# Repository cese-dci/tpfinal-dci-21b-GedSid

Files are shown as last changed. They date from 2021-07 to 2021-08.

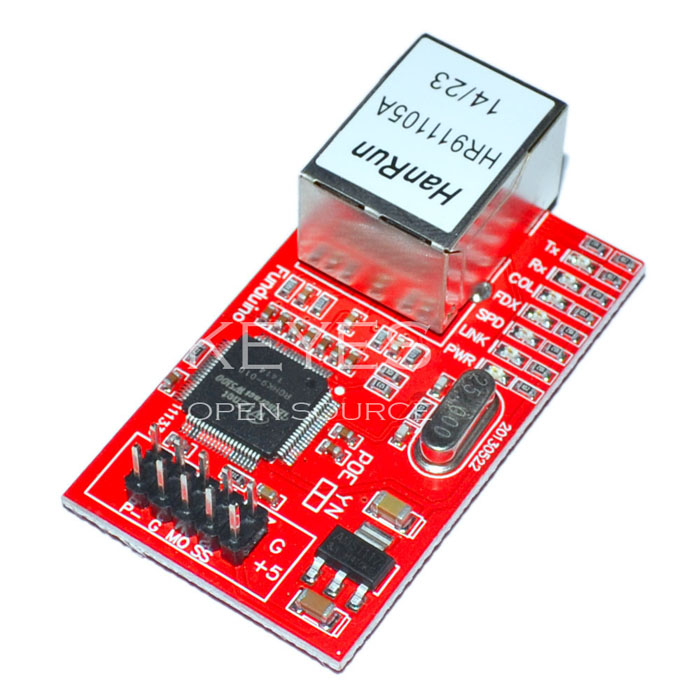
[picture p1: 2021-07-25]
doc/propuesta/Wiznet-w5100-ethernet-module-top.jpg

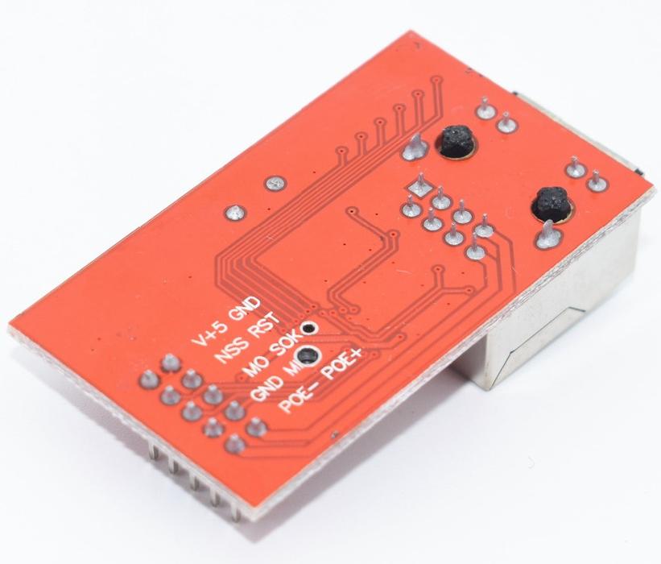
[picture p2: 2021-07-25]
doc/propuesta/Wiznet-w5100-ethernet-module-botton.jpg

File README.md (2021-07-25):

## Trabajo práctico final de la asignatura DCI ##
Este repositorio contiene el trabajo práctico final para la asignatura de Diseño de Circuitos Impresos de la carrera de posgrado de FIUBA.

* Autor: JOAQUIN ULLOA
* Título corto del trabajo:  Réplica Módulo Ethernet W5100 Mini
* Descripción:  La placa tiene un regulador de tensión, por lo que puede se pueden usar tensiones de entrada de 5 V a 12 V. Los pines de señal admiten niveles de 3,3 V y 5 V. El Módulo Ethernet tiene un conector RJ-45 estándar, con un transformador de línea integrado.

## Licencia de este trabajo ##
XXXMENCIONAR ACÁ LA LICENCIAXXX (Editar este párrafo) 
Y además colcar el archivo de texto de la misma en el directorio raíz.
Para este TP se pide que la licencia sea de hardware abierto.
Ver la sección "What license should I use?": https://www.oshwa.org/faq/

## Estructura del TP FINAL ##

Se propone y se pide utilizar la siguiente estructura.

* doc: Toda la información sobre el circuito, principalmente de autoría o procesamiento propio. Por ejemplo:
  * Notas de ingeniería propias.
  * Notas de aplicación propias.
  * Estudios previos, estado del arte, resumen de las investigaciones.
  * Notas con cálculos.
  * Dibujos adicionales.
  * Fotos de los prototipos.
  * Presupuestos, cotizaciones.
* info: Toda la iformación recolectada, principalmente de terceros, como por ejemplo:
  * Hojas de datos.
  * Notas de aplicación.
  * Info de productos comerciales.
  * Info en internet.
* pcb: Archivos de diseño esquemático y pcb.

Dependiendo la magnitud del proyecto, tendremos más o menos información en estos directorios. 
Revisar los README.md en cada directorio para conocer las pautas de cada uno para este TP.

NOTA: El alumno puede y debe borrar de este archivo todo lo que considere necesario, por ejemplo las aclaraciones del docente y esta misma nota.

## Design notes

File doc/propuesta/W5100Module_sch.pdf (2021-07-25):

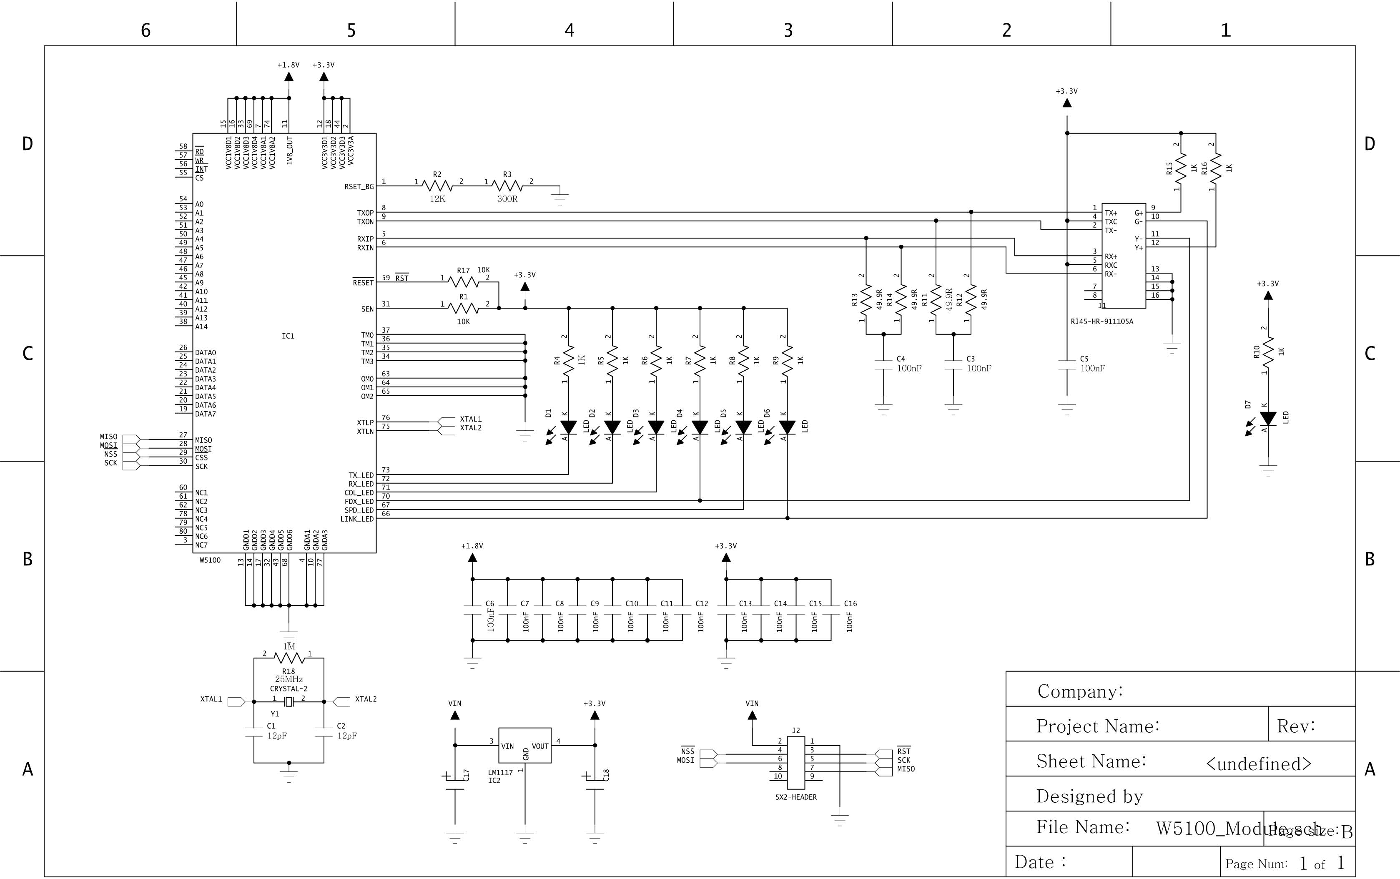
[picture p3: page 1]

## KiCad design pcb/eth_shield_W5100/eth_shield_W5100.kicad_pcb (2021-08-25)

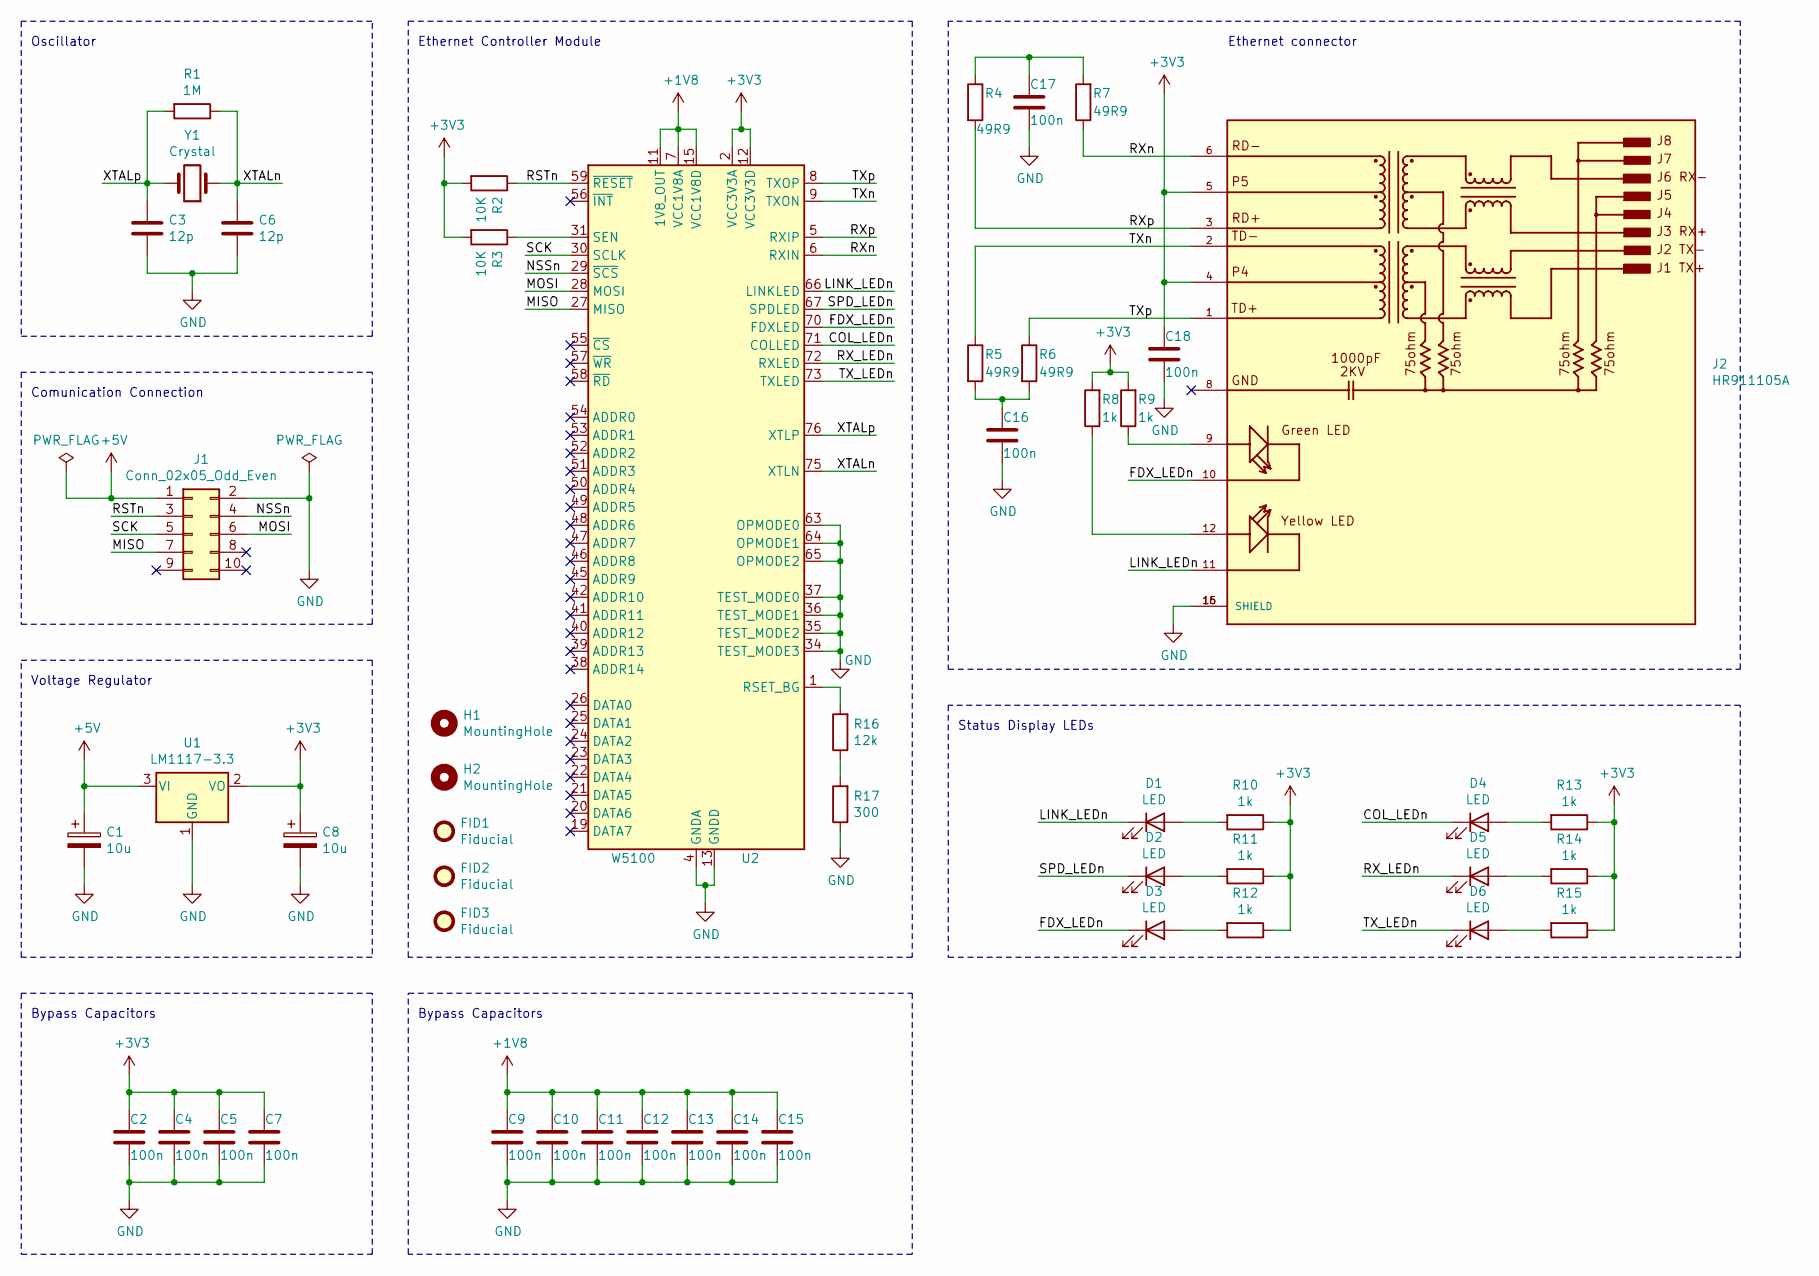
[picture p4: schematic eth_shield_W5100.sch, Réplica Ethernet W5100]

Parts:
C1: 10u; C_0805_2012Metric_Pad1.15x1.40mm_HandSolder
C2, C4, C5, C7, C9, C10, C11, C12, C13, C14, C15, C16, C17, C18: 100n; C_0603_1608Metric_Pad1.05x0.95mm_HandSolder
C3, C6: 12p; C_0603_1608Metric_Pad1.05x0.95mm_HandSolder
C8: 10u; C_0603_1608Metric_Pad1.05x0.95mm_HandSolder
D1, D2, D3, D4, D5, D6: LED; LED_0603_1608Metric_Pad1.05x0.95mm_HandSolder
FID1, FID2, FID3: Fiducial; Fiducial_0.75mm_Mask1.5mm
H1, H2: MountingHole; MountingHole_2.1mm
J1: Conn_02x05_Odd_Even; PinSocket_2x05_P2.54mm_Vertical
J2: HR911105A; PARTREV A
R1: 1M; R_0603_1608Metric_Pad0.98x0.95mm_HandSolder
R2, R3: 10K; R_0603_1608Metric_Pad0.98x0.95mm_HandSolder
R4, R5, R6, R7: 49R9; R_0603_1608Metric_Pad0.98x0.95mm_HandSolder
R8, R9, R10, R11, R12, R13, R14, R15: 1k; R_0603_1608Metric_Pad0.98x0.95mm_HandSolder
R16: 12k; R_0603_1608Metric_Pad0.98x0.95mm_HandSolder
R17: 300; R_0603_1608Metric_Pad0.98x0.95mm_HandSolder
U1: LM1117-3.3; SOT-223-3_TabPin2; Manufacturer PN LM1117IMPX-3.3/NOPB
U2: W5100; LQFP-80_10x10mm_P0.4mm; Manufacturer PN W5100
Y1: Crystal; Crystal_HC18-U_Vertical; Manufacturer PN ECS-200-18-4X-CKM

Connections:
+1V8: C9.1, C10.1, C11.1, C12.1, C13.1, C14.1, C15.1, U2.7 (VCC1V8A), U2.11 (1V8_OUT), U2.15 (VCC1V8D), U2.16 (VCC1V8D), U2.33 (VCC1V8D), U2.69 (VCC1V8D), U2.74 (VCC1V8A)
+3V3: C2.1, C4.1, C5.1, C7.1, C8.1, C18.1, J2.4, J2.5, R2.2, R3.2, R8.2, R9.2, R10.1, R11.1, R12.1, R13.1, R14.1, R15.1, U1.2 (VO), U2.2 (VCC3V3A), U2.12 (VCC3V3D), U2.18 (VCC3V3D), U2.44 (VCC3V3D)
+5V: C1.1, J1.1, U1.3 (VI)
/COL_LEDn: D4.1 (K), U2.71 (COLLED)
/FDX_LEDn: D3.1 (K), J2.10, U2.70 (FDXLED)
/LINK_LEDn: D1.1 (K), J2.11, U2.66 (LINKLED)
/MISO: J1.7, U2.27 (MISO)
/MOSI: J1.6, U2.28 (MOSI)
/NSSn: J1.4, U2.29 (~SCS)
/RSTn: J1.3, R2.1, U2.59 (~RESET)
/RX_LEDn: D5.1 (K), U2.72 (RXLED)
/RXn: J2.6, R7.1, U2.6 (RXIN)
/RXp: J2.3, R4.2, U2.5 (RXIP)
/SCK: J1.5, U2.30 (SCLK)
/SPD_LEDn: D2.1 (K), U2.67 (SPDLED)
/TX_LEDn: D6.1 (K), U2.73 (TXLED)
/TXn: J2.2, R5.1, U2.9 (TXON)
/TXp: J2.1, R6.1, U2.8 (TXOP)
/XTALn: C6.1, R1.1, U2.75 (XTLN), Y1.1
/XTALp: C3.1, R1.2, U2.76 (XTLP), Y1.2
GND: C1.2, C2.2, C3.2, C4.2, C5.2, C6.2, C7.2, C8.2, C9.2, C10.2, C11.2, C12.2, C13.2, C14.2, C15.2, C16.2, C17.2, C18.2, J1.2, J2.15 (SHIELD), J2.16 (SHIELD), R17.1, U1.1 (GND), U2.4 (GNDA), U2.10 (GNDA), U2.13 (GNDD), U2.14 (GNDD), U2.17 (GNDD), U2.32 (GNDD), U2.34 (TEST_MODE3), U2.35 (TEST_MODE2), U2.36 (TEST_MODE1), U2.37 (TEST_MODE0), U2.43 (GNDD), U2.63 (OPMODE0), U2.64 (OPMODE1), U2.65 (OPMODE2), U2.68 (GNDD), U2.77 (GNDA)
unnamed: C16.1, R5.2, R6.2
unnamed: C17.1, R4.1, R7.2
unnamed: D1.2 (A), R10.2
unnamed: D2.2 (A), R11.2
unnamed: D3.2 (A), R12.2
unnamed: D4.2 (A), R13.2
unnamed: D5.2 (A), R14.2
unnamed: D6.2 (A), R15.2
unnamed: J2.9, R9.1
unnamed: J2.12, R8.1
unnamed: R3.1, U2.31 (SEN)
unnamed: R16.1, R17.2
unnamed: R16.2, U2.1 (RSET_BG)

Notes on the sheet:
Bypass Capacitors
Oscillator
Ethernet Controller Module
Ethernet connector
Status Display LEDs
Voltage Regulator
Comunication Connection

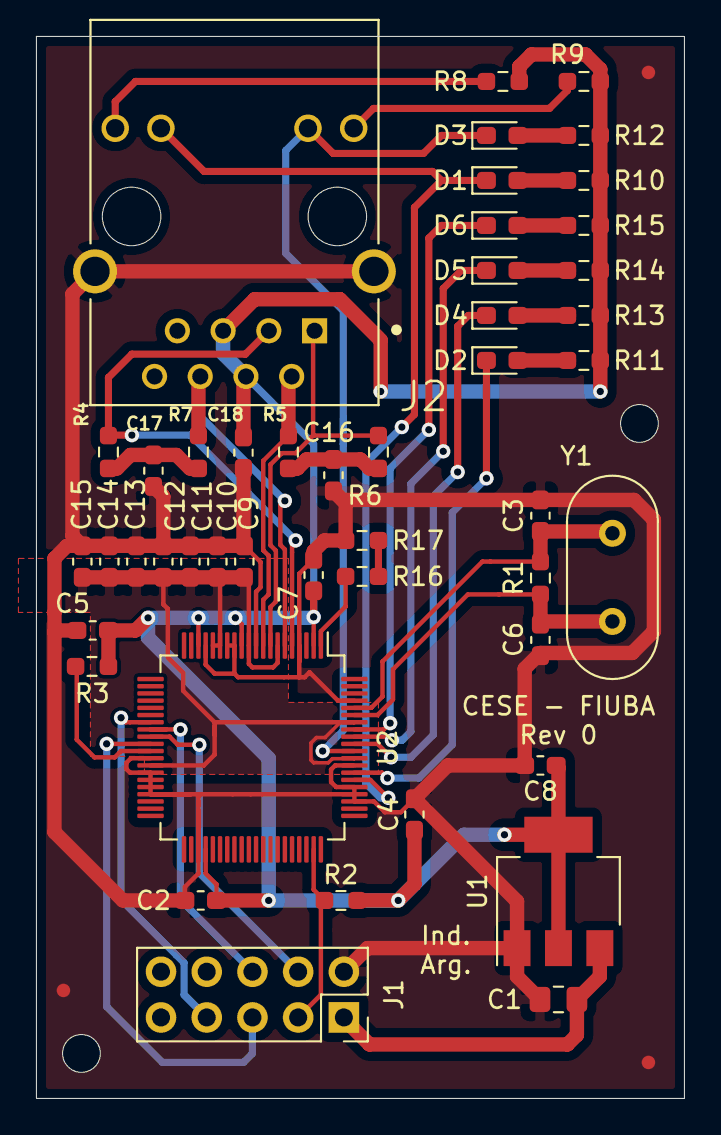
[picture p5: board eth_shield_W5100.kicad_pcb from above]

Board: 2 copper layers, 36.0 x 59.0 mm, 51 parts (0 on the bottom side), 34 nets.

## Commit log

2021-07-25 Se agregan los archivos de la propuesta, los datasheet relevantes, las bibliotecas y el esquemático completo
    [eth_shield_W5100.kicad_pcb, eth_shield_W5100.sch]
2021-07-25 Se agraga la asociación de componentes y la netlist
    [eth_shield_W5100.sch]
2021-08-02 Se agregan los modelos 3D que faltan y se comienza eel routeo
    [eth_shield_W5100.kicad_pcb]
2021-08-10 Se termina el routeo, se agregan comentarios y detalles
    [eth_shield_W5100.kicad_pcb, eth_shield_W5100.sch]
2021-08-12 Se agrega agujeros y se hacen las correciones indicadas por el docente
    [eth_shield_W5100.kicad_pcb, eth_shield_W5100.sch]
2021-08-25 Se agregan las correciones que se hicieron para la presentación
    [eth_shield_W5100.kicad_pcb, eth_shield_W5100.sch]
